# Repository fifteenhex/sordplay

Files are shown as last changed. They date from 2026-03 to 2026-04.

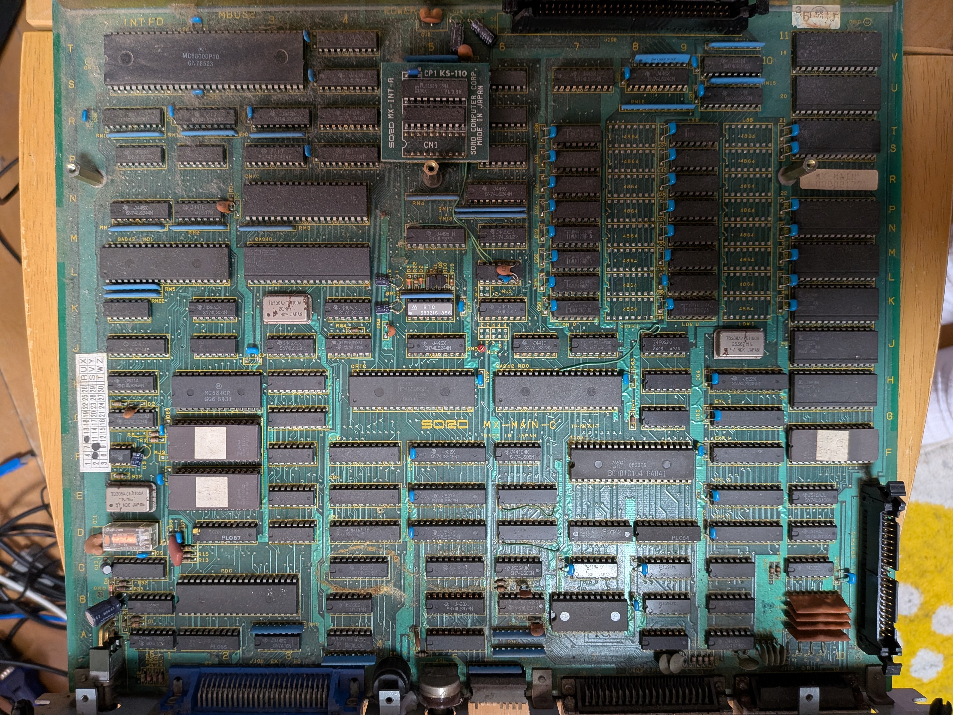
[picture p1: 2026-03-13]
MX-MAIN-C-front.jpg

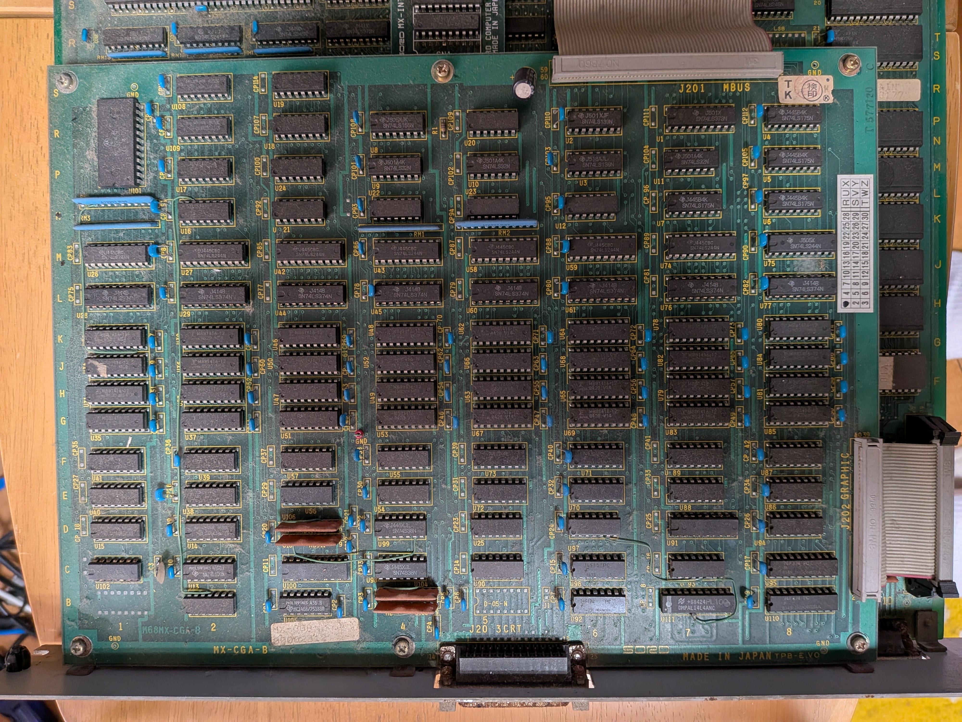
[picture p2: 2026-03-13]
MX-CGA-B-front.jpg

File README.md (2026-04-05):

# MX-MAIN-C

The markings on some of the chips on this board are barely visible. Some totally missing.

| | 1 | 2 | 3 | 4 | 5 | 6 | 7 | 8 | 9 | 10 | 11 | |
|---|---|---|---|---|---|---|---|---|---|---|---|---|
| t | * | * | * | SN74LS245N  | | | | | | MB83256 (019 RA) | * | v |
| s | mc68000 | * | * | SN74LS245N  | | | | | | MB83256 (020 RA) | * | u |
| r | HD74LS245WP | HD74LS245WP | SN74LS245N  | SN74LS373N  | | 4864 | (4864) | 4864 | (4864) | * | * | t |
| p | SN74LS670N  | SN74LS670N | HD74LS245WP | HD74LS245WP | | 4864 | (4864) | 4864 | (4864) | MB83256 (021 RA) | * | s |
| n | SN74LS244N  | SN7417N | ?8257c-2 | * | | 4864 | (4864) | 4864 | (4864) | (serial sticker) | * | r |
| | | | | | | 4864 | (4864) | 4864 | (4864) | * | * | p |
| | | | | | | 4864 | (4864) | 4864 | (4864) | MB83256 (022 RA) | * | n |
| | | | | | | 4864 | (4864) | 4864 | (4864) | * | * | m |
| l | | | ga040 | * | | 4864 | (4864) | 4864 | (4864) | MB83256 (027 RA) | * | l |
| k | | SN74LS04N | 20mhz xtal  | SN74LS04N | | 4864 | (4864) | 4864 | (4864) | MB83256 (028 RA) | * | k |
| j | HD74LS244P  | 74F08PC | SN74LS155N  | | | | | | 26.667mhz xtal | MB83256 (029 RA) | * | j |
| h | SN74LS259N  | MC6840P | | | | | | | SN74LS646NT | MB83256 (030 RA) | * | h |
| g | SN74LS123N  | | | | | | | | MB8416A-15L-SK (EKL 1) | | | g |
| f | SN75452BP | MBM2764-20 (?even? ROM) | | MB8416A-15L | SN74LS646NT | SN74LS08N | GA041 (NEC gate array?) | * | MB8416A-15L-SK (EKR 1) | D2764D (M68MX CG) | * | f |
| e | 16mhz xtal  | MBM2764-20 (ODD ROM) | | MB8416A-15L | SN74LS646NT | | | | MB8416A-15L-SK (EKL 0) | SN74LS138N | - | e |
| d | relay? | | SN74LS157N  | MB8416A-15L | SN74LS646NT | | PL042 | PL084 | MB8416A-15L-SK (EKR 0) | SN74LS138N | - | d |
| c | SED9421 | | | SN74LS245N  | SN74LS245N  | SN74LS86N | 74F194PC | 74F194PC | | SN7416N | - | c |
| b | SN7416N | ?NEC FDC? | * | SN7416N | SN74LS373N  | SN74LS123N | HD6850P (ACIA KB) | 74F194PC | | * | - | b |
| a | SN74LS00N | CK2605 - PL085 | SN7416N | SN74LS14N | SN74LS244N  | resistor packs | (space) | ?SN75189AN? | ?SN75188AN? | (orange hybrid * 4) | (graphics connector) | a |
| |  1 | 2 | 3 | 4 | 5 | 6 | 7 | 8 | 9 | 10 | 10 | |

- mc68000 reset -> 4 + 11 of n2
- reset sw -> a1 -> 4b -> r32+r33
-MB83256 roms are Kanji roms -> https://haserin09.la.coocan.jp/kanji_rom.html
- Buzzer goes to pin 5 on f1 which is 2y, 2a goes to h2 pin 6, which is o3 of the PTM, 2b goes to g1 pin 5

- 
-Other roms are the same as the dumps here: https://archive.org/details/sordm68mxrom, confirmed by dumping the roms from my board and comparing.
- There is space for 256KB of 4864s but only half are populated, my board has 41256s though.
- The numbers on the edge connector side and the numbers on the face plate side are a bit confusing around 10

- dip 2 controls the beep on boot? Don't think so anymore..

- Character port serial txd goes to A9 pin 3, which is a line driver, which makes sense

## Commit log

2026-03-13 Add photo of graphics board
2026-03-23 Start adding a kicad schematic of mx-main-c for debugging why it no work
    [MX-MAIN-C.kicad_pcb, MX-MAIN-C.kicad_sch]
2026-03-26 kicad schematic updates
    [MX-MAIN-C.kicad_sch]
2026-03-29 schematic updates
    [MX-MAIN-C.kicad_sch]
2026-03-29 skeleton for a test rom to work out why the board no work
2026-04-03 kicad schematic update
    [MX-MAIN-C.kicad_sch]
2026-04-04 Update schematic
    [MX-MAIN-C.kicad_sch]
